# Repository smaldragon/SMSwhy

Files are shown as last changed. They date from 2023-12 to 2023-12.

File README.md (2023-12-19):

# SMSwhy

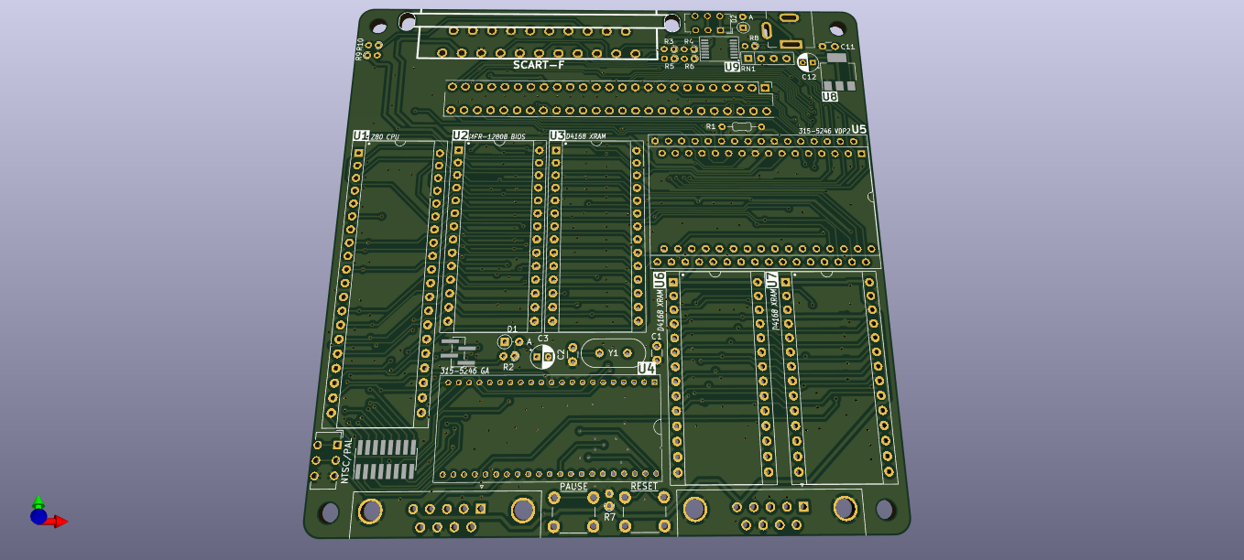
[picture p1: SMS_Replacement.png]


This is an alternate Sega Master System motherboard in a 10cmX10cm format.

## Why

Felt like it

## Should I use it

Short Answer: No. It's 100% untested and I'm not sure there is even enough clearance for cartridges to plug in

## What can I do with this?

It's released under the unlicense, so feel free to modify it to your heart's content. You can also use the schematic for a resonable-sized board if you want. But remember: This is all untested and might have mistakes, so uh, double check everything if you go that route.

## What revisions is this board compatible with?

This was designed for the chips present in the "Master System II Power Base RGB" (the later french revision which lacks IC9), with a Alex Kidd bios. The output is RGB via scart.

## What additional chips are here that weren't in the original board?

A AMS1117 5volt regulator and a THS7375 video amplifier, both are SMD parts and still active as of writing of this readme

## Any additions?

It has a RESET button, a PAL/NTSC selector switch, room for a power LED, and some 1.27mm headers that could be used to install a (custom) designed FM board.

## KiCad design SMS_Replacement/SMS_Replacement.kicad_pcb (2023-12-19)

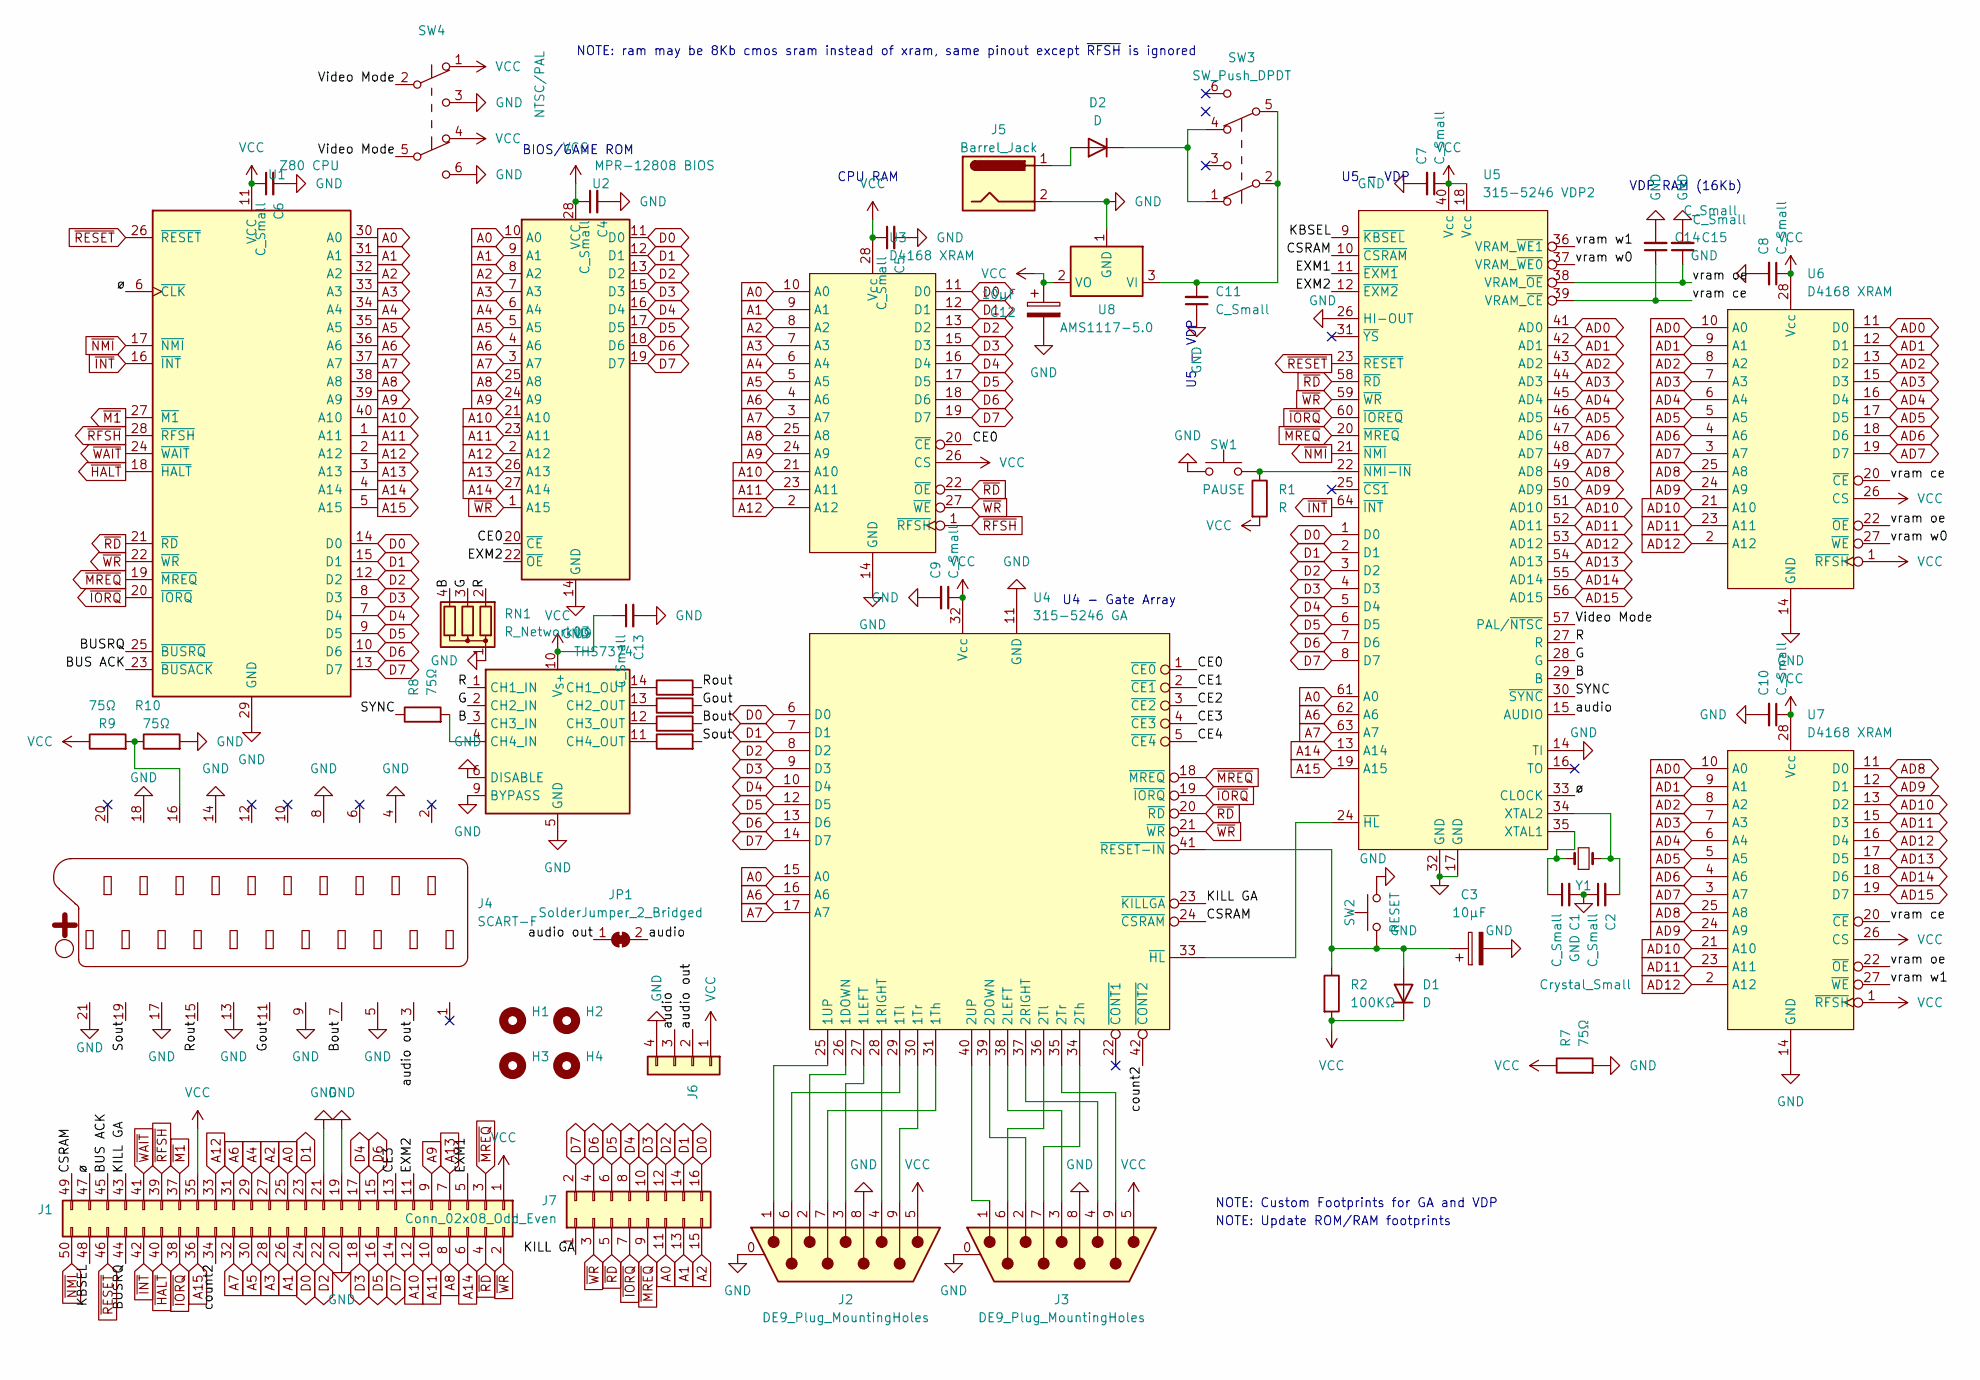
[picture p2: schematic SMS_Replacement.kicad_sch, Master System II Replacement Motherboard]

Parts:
C1, C2, C11: C_Small; C_Disc_D3.0mm_W1.6mm_P2.50mm
C3, C12: 10µF; CP_Radial_D4.0mm_P2.00mm
C4, C5, C6, C7, C8, C9, C10, C13, C14, C15: C_Small; C_1206_3216Metric
D1, D2: D; D_DO-34_SOD68_P2.54mm_Vertical_AnodeUp
H1, H2, H3, H4: MountingHole; MountingHole_3.2mm_M3_DIN965
J1: Conn_02x25_Odd_Even; PinHeader_2x25_P2.54mm_Vertical
J2, J3: DE9_Plug_MountingHoles; DSUB-9_Female_Horizontal_P2.77x2.84mm_EdgePinOffset4.94mm_H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
J4: SCART-F; SCART
J5: Barrel_Jack; BarrelJack_Kycon_KLDX-0202-xC_Horizontal
J6: Conn_01x04; PinHeader_1x04_P1.27mm_Vertical_SMD_Pin1Left
J7: Conn_02x08_Odd_Even; PinHeader_2x08_P1.27mm_Vertical_SMD
JP1: SolderJumper_2_Bridged; SolderJumper-2_P1.3mm_Bridged_Pad1.0x1.5mm
R1: R; R_Axial_DIN0204_L3.6mm_D1.6mm_P7.62mm_Horizontal
R2: 100KΩ; R_Axial_DIN0204_L3.6mm_D1.6mm_P1.90mm_Vertical
R3, R4, R5, R6, R7, R8, R9, R10: 75Ω; R_Axial_DIN0204_L3.6mm_D1.6mm_P1.90mm_Vertical
RN1: R_Network03; R_Array_SIP4
SW1: PAUSE; SW_PUSH_6mm_H13mm
SW2: RESET; SW_PUSH_6mm_H13mm
SW3: SW_Push_DPDT; SW_CuK_JS202011AQN_DPDT_Angled
SW4: NTSC/PAL; SW_CuK_JS202011AQN_DPDT_Angled
U1: Z80 CPU; DIP-40_W15.24mm_Socket
U2: MPR-12808 BIOS; DIP-28_W15.24mm_Socket
U3, U6, U7: D4168 XRAM; DIP-28_W15.24mm_Socket
U4: 315-5246 GA; SDIP-42
U5: 315-5246 VDP2; QIP-64_W22.86mm_Socket
U8: AMS1117-5.0; SOT-223-3_TabPin2
U9: THS7374; TSSOP-14_4.4x5mm_P0.65mm
Y1: Crystal_Small; Crystal_HC49-U_Vertical

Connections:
/B: RN1.4 (R3), U5.29 (B), U9.3 (CH3_IN)
/BUS ACK: J1.45, U1.23 (~BUSACK)
/BUSRQ: J1.44, U1.25 (~BUSRQ)
/Bout: J4.7, R4.2
/CE0: U2.20 (~CE), U3.20 (~CE), U4.1 (~CE0)
/CE1: U4.2 (~CE1)
/CE2: U4.3 (~CE2)
/CE3: J1.13, U4.4 (~CE3)
/CE4: U4.5 (~CE4)
/CSRAM: J1.49, U4.24 (~CSRAM), U5.10 (~CSRAM)
/EXM1: J1.5, U5.11 (~EXM1)
/EXM2: J1.11, U2.22 (~OE), U5.12 (~EXM2)
/G: RN1.3 (R2), U5.28 (G), U9.2 (CH2_IN)
/Gout: J4.11, R5.2
/KBSEL: J1.48, U5.9 (~KBSEL)
/KILL GA: J1.43, J7.1, U4.23 (~KILLGA)
/R: RN1.2 (R1), U5.27 (R), U9.1 (CH1_IN)
/Rout: J4.15, R6.2
/SYNC: R8.1, U5.30 (~SYNC)
/Sout: J4.19, R3.2
/Video Mode: SW4.2 (B), SW4.5 (B), U5.57 (PAL/~NTSC)
/audio: J6.3, JP1.2 (B), U5.15 (AUDIO)
/audio out: J4.3, J6.2, JP1.1 (A)
/count2: J1.34, U4.42 (~CONT2)
/vram ce: C14.1, U5.39 (VRAM_~CE), U6.20 (~CE), U7.20 (~CE)
/vram oe: C15.1, U5.38 (VRAM_~OE), U6.22 (~OE), U7.22 (~OE)
/vram w0: U5.37 (VRAM_~WE0), U6.27 (~WE)
/vram w1: U5.36 (VRAM_~WE1), U7.27 (~WE)
/ø: J1.47, U1.6 (~CLK), U5.33 (CLOCK)
A0: J1.25, J7.11, U1.30 (A0), U2.10 (A0), U3.10 (A0), U4.15 (A0), U5.61 (A0)
A1: J1.26, J7.13, U1.31 (A1), U2.9 (A1), U3.9 (A1)
A2: J1.27, J7.15, U1.32 (A2), U2.8 (A2), U3.8 (A2)
A3: J1.28, U1.33 (A3), U2.7 (A3), U3.7 (A3)
A4: J1.29, U1.34 (A4), U2.6 (A4), U3.6 (A4)
A5: J1.30, U1.35 (A5), U2.5 (A5), U3.5 (A5)
A6: J1.31, U1.36 (A6), U2.4 (A6), U3.4 (A6), U4.16 (A6), U5.62 (A6)
A7: J1.32, U1.37 (A7), U2.3 (A7), U3.3 (A7), U4.17 (A7), U5.63 (A7)
A8: J1.8, U1.38 (A8), U2.25 (A8), U3.25 (A8)
A9: J1.9, U1.39 (A9), U2.24 (A9), U3.24 (A9)
A10: J1.12, U1.40 (A10), U2.21 (A10), U3.21 (A10)
A11: J1.10, U1.1 (A11), U2.23 (A11), U3.23 (A11)
A12: J1.33, U1.2 (A12), U2.2 (A12), U3.2 (A12)
A13: J1.7, U1.3 (A13), U2.26 (A13)
A14: J1.6, U1.4 (A14), U2.27 (A14), U5.13 (A14)
A15: J1.36, U1.5 (A15), U5.19 (A15)
AD0: U5.41 (AD0), U6.10 (A0), U6.11 (D0), U7.10 (A0)
AD1: U5.42 (AD1), U6.9 (A1), U6.12 (D1), U7.9 (A1)
AD2: U5.43 (AD2), U6.8 (A2), U6.13 (D2), U7.8 (A2)
AD3: U5.44 (AD3), U6.7 (A3), U6.15 (D3), U7.7 (A3)
AD4: U5.45 (AD4), U6.6 (A4), U6.16 (D4), U7.6 (A4)
AD5: U5.46 (AD5), U6.5 (A5), U6.17 (D5), U7.5 (A5)
AD6: U5.47 (AD6), U6.4 (A6), U6.18 (D6), U7.4 (A6)
AD7: U5.48 (AD7), U6.3 (A7), U6.19 (D7), U7.3 (A7)
AD8: U5.49 (AD8), U6.25 (A8), U7.11 (D0), U7.25 (A8)
AD9: U5.50 (AD9), U6.24 (A9), U7.12 (D1), U7.24 (A9)
AD10: U5.51 (AD10), U6.21 (A10), U7.13 (D2), U7.21 (A10)
AD11: U5.52 (AD11), U6.23 (A11), U7.15 (D3), U7.23 (A11)
AD12: U5.53 (AD12), U6.2 (A12), U7.2 (A12), U7.16 (D4)
AD13: U5.54 (AD13), U7.17 (D5)
AD14: U5.55 (AD14), U7.18 (D6)
AD15: U5.56 (AD15), U7.19 (D7)
D0: J1.24, J7.16, U1.14 (D0), U2.11 (D0), U3.11 (D0), U4.6 (D0), U5.1 (D0)
D1: J1.23, J7.14, U1.15 (D1), U2.12 (D1), U3.12 (D1), U4.7 (D1), U5.2 (D1)
D2: J1.22, J7.12, U1.12 (D2), U2.13 (D2), U3.13 (D2), U4.8 (D2), U5.3 (D2)
D3: J1.18, J7.10, U1.8 (D3), U2.15 (D3), U3.15 (D3), U4.9 (D3), U5.4 (D3)
D4: J1.17, J7.8, U1.7 (D4), U2.16 (D4), U3.16 (D4), U4.10 (D4), U5.5 (D4)
D5: J1.16, J7.6, U1.9 (D5), U2.17 (D5), U3.17 (D5), U4.12 (D5), U5.6 (D5)
D6: J1.15, J7.4, U1.10 (D6), U2.18 (D6), U3.18 (D6), U4.13 (D6), U5.7 (D6)
D7: J1.14, J7.2, U1.13 (D7), U2.19 (D7), U3.19 (D7), U4.14 (D7), U5.8 (D7)
GND: C1.2, C2.1, C3.2, C4.2, C5.2, C6.2, C7.2, C8.2, C9.2, C10.2, C11.1, C12.2, C13.2, C14.2, C15.2, J1.19, J1.20, J1.21, J2.0 (PAD), J2.8, J3.0 (PAD), J3.8, J4.4, J4.5, J4.8, J4.9, J4.13, J4.14, J4.17, J4.18, J4.21, J5.2, J6.4, R7.2, R10.2, RN1.1 (common), SW1.1, SW2.2, SW4.3 (C), SW4.6 (C), U1.29 (GND), U2.14 (GND), U3.14 (GND), U4.11 (GND), U5.14 (TI), U5.17 (GND), U5.26 (HI-OUT), U5.32 (GND), U6.14 (GND), U7.14 (GND), U8.1 (GND), U9.5 (GND), U9.6 (DISABLE), U9.9 (BYPASS)
unnamed: C3.1, D1.2 (A), R2.1, SW2.1, U4.41 (~RESET-IN)
unnamed: D2.2 (A), J5.1
unnamed: D2.1 (K), SW3.1 (A), SW3.4 (A)
unnamed: J4.16, R9.2, R10.1
unnamed: J2.2, U4.26 (1DOWN)
unnamed: J2.3, U4.27 (1LEFT)
unnamed: J2.4, U4.28 (1RIGHT)
unnamed: J2.7, U4.31 (1Th)
unnamed: J2.6, U4.29 (1Tl)
unnamed: J2.9, U4.30 (1Tr)
unnamed: J2.1, U4.25 (1UP)
unnamed: J3.2, U4.39 (2DOWN)
unnamed: J3.3, U4.38 (2LEFT)
unnamed: J3.4, U4.37 (2RIGHT)
unnamed: J3.7, U4.34 (2Th)
unnamed: J3.6, U4.36 (2Tl)
unnamed: J3.9, U4.35 (2Tr)
unnamed: J3.1, U4.40 (2UP)
unnamed: U4.33 (~HL), U5.24 (~HL)
unnamed: C1.1, U5.35 (XTAL1), Y1.1
unnamed: C2.2, U5.34 (XTAL2), Y1.2
unnamed: R1.1, SW1.2, U5.22 (~NMI-IN)
unnamed: C11.2, SW3.2 (B), SW3.5 (B), U8.3 (VI)
unnamed: R6.1, U9.14 (CH1_OUT)
unnamed: R5.1, U9.13 (CH2_OUT)
unnamed: R4.1, U9.12 (CH3_OUT)
unnamed: R8.2, U9.4 (CH4_IN)
unnamed: R3.1, U9.11 (CH4_OUT)
VCC: C4.1, C5.1, C6.1, C7.1, C8.1, C9.1, C10.1, C12.1, C13.1, D1.1 (K), J1.1, J1.35, J2.5, J3.5, J6.1, R1.2, R2.2, R7.1, R9.1, SW4.1 (A), SW4.4 (A), U1.11 (VCC), U2.28 (VCC), U3.26 (CS), U3.28 (Vcc), U4.32 (Vcc), U5.18 (Vcc), U5.40 (Vcc), U6.1 (~RFSH), U6.26 (CS), U6.28 (Vcc), U7.1 (~RFSH), U7.26 (CS), U7.28 (Vcc), U8.2 (VO), U9.10 (V_{S+})
~HALT: J1.40, U1.18 (~HALT)
~INT: J1.42, U1.16 (~INT), U5.64 (~INT)
~IORQ: J1.38, J7.7, U1.20 (~IORQ), U4.19 (~IORQ), U5.60 (~IOREQ)
~M1: J1.37, U1.27 (~M1)
~MREQ: J1.3, J7.9, U1.19 (~MREQ), U4.18 (~MREQ), U5.20 (~MREQ)
~NMI: J1.50, U1.17 (~NMI), U5.21 (~NMI)
~RD: J1.4, J7.5, U1.21 (~RD), U3.22 (~OE), U4.20 (~RD), U5.58 (~RD)
~RESET: J1.46, U1.26 (~RESET), U5.23 (~RESET)
~RFSH: J1.39, U1.28 (~RFSH), U3.1 (~RFSH)
~WAIT: J1.41, U1.24 (~WAIT)
~WR: J1.2, J7.3, U1.22 (~WR), U2.1 (A15), U3.27 (~WE), U4.21 (~WR), U5.59 (~WR)

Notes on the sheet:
U4 - Gate Array
BIOS/GAME ROM
VDP RAM (16Kb)
U5 - VDP
CPU RAM
NOTE: ram may be 8Kb cmos sram instead of xram, same pinout except ~{RFSH} is ignored
NOTE: Custom Footprints for GA and VDP
NOTE: Update ROM/RAM footprints

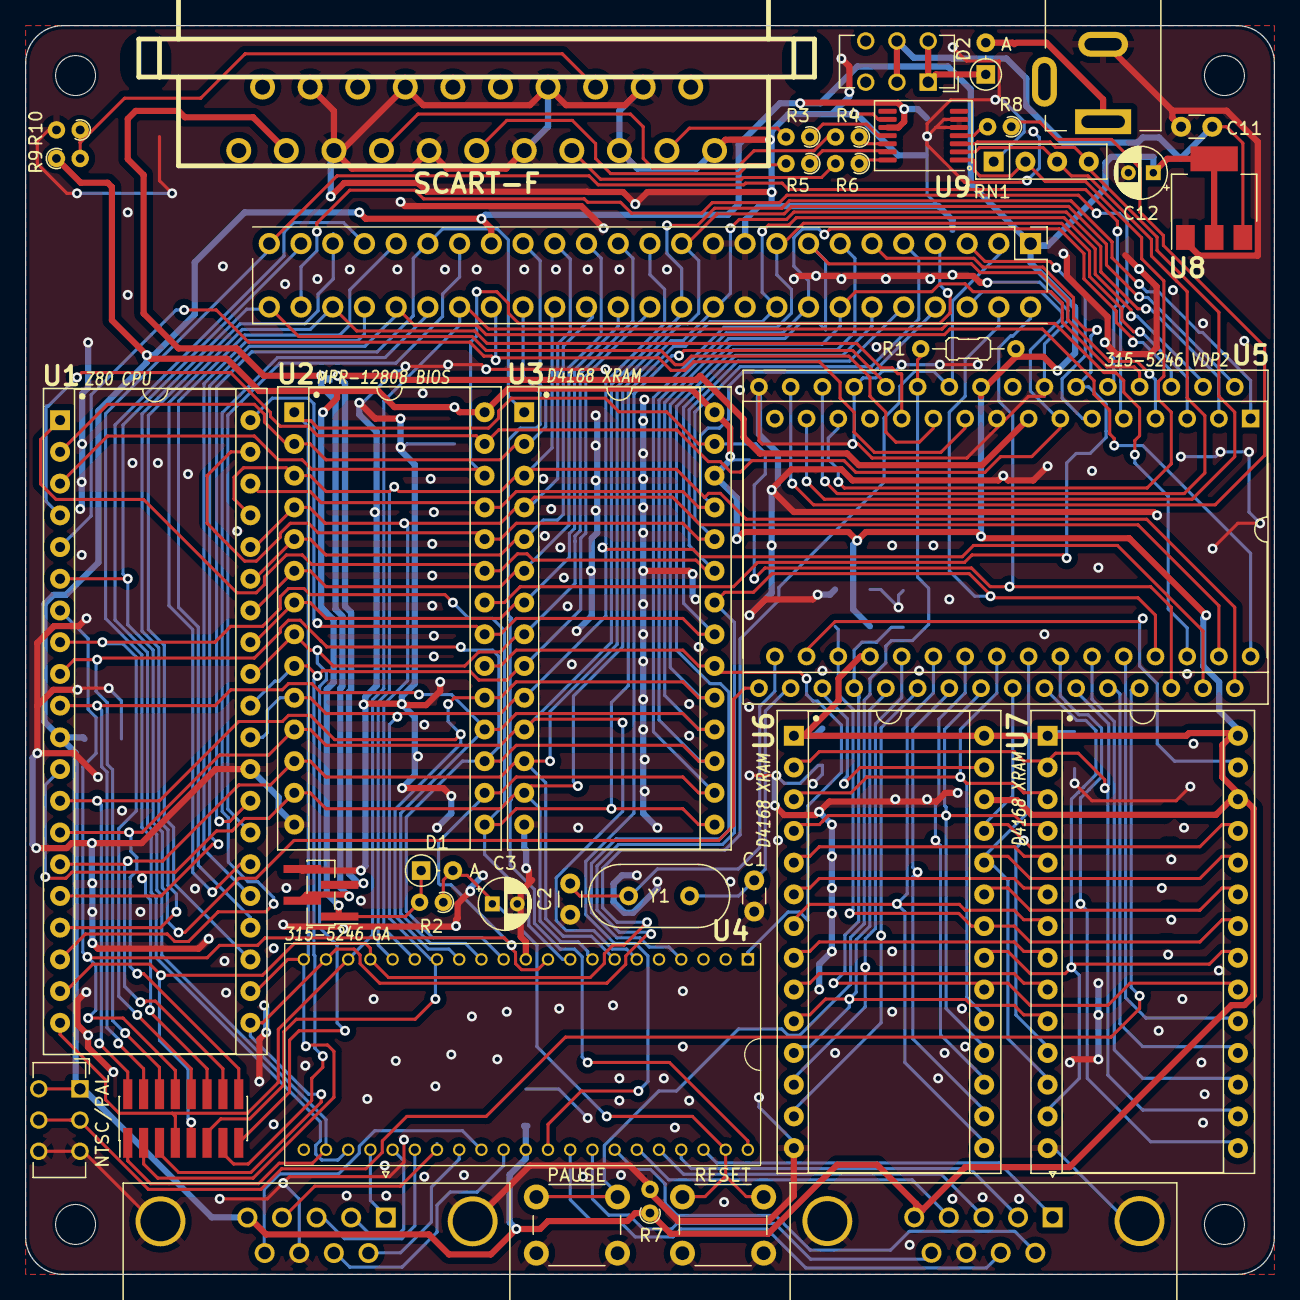
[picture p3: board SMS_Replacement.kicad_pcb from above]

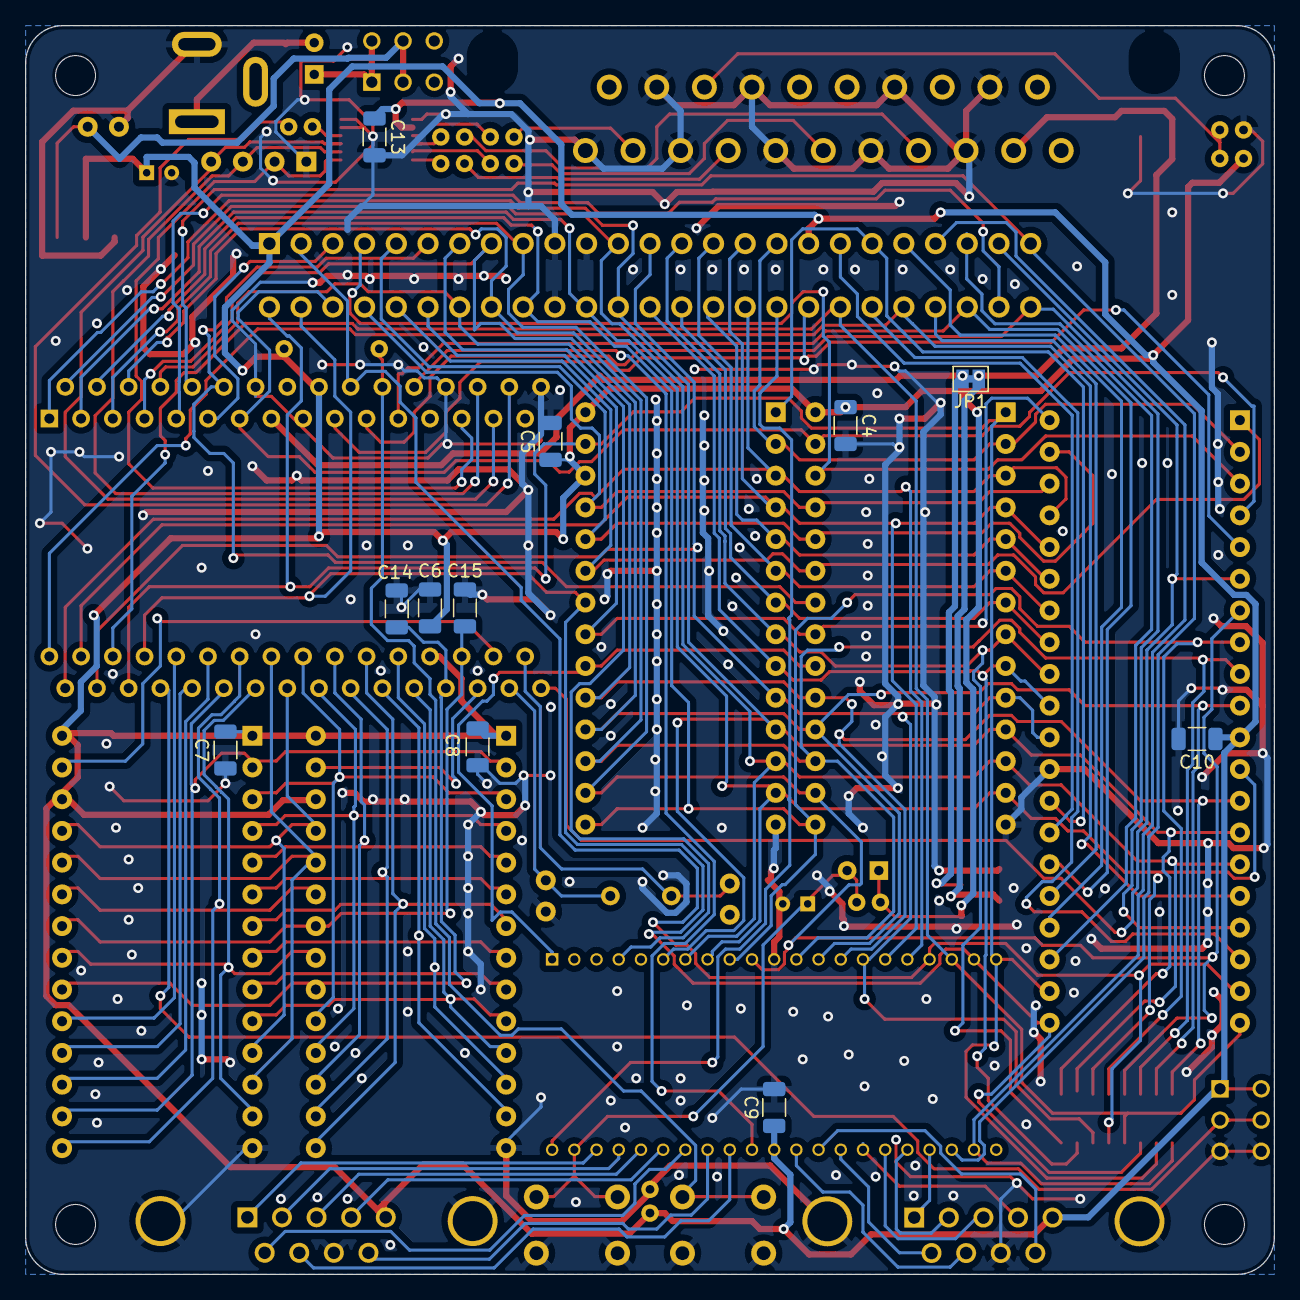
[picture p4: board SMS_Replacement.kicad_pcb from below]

Board: 4 copper layers, 100.0 x 100.0 mm, 54 parts (11 on the bottom side), 107 nets.
